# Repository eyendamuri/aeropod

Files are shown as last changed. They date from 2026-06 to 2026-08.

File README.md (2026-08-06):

# aeropod

**A handheld music player built from scratch: custom hardware, custom firmware, custom everything.**

aeropod is an iPod-inspired portable media player built around an ESP32. It has a
capacitive click wheel, a 240×320 colour display, and plays music three different
ways: local files from a microSD card, **Spotify** (both as a Spotify Connect
speaker *and* through the Web API), and as a **Bluetooth speaker** over A2DP. It
even plays MJPEG video. Everything runs on a custom 4-layer circuit board I
designed, inside a 3D-printed case.

<!-- PHOTO: hero shot of the finished aeropod in your hand. Drop the file in docs/images/ and update the path below. -->
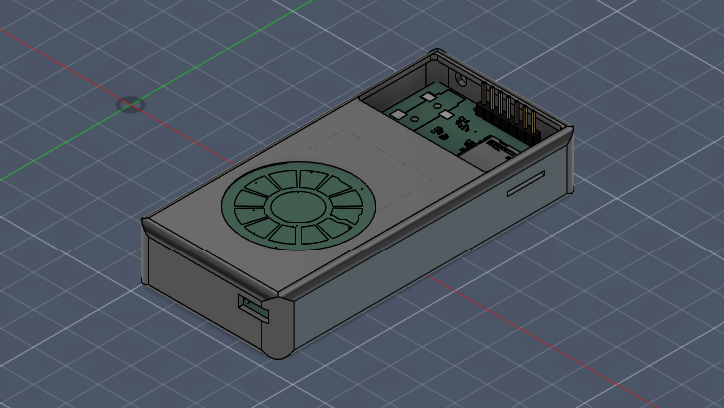
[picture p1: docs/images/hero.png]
aeropod


---

## What it does

- **Local playback**: MP3 / AAC / WAV streamed off a microSD card, browsed by Artist → Album → Track
- **Spotify**: log in once on your phone, then control playback and stream straight to the device. aeropod also announces itself as a **Spotify Connect** target, so you can pick it as a speaker from the Spotify app
- **Bluetooth audio** works both ways: use aeropod as a Bluetooth *speaker* (A2DP sink) from your phone, or have it stream *out* to Bluetooth headphones (A2DP source). AVRCP play/pause/skip supported in both directions
- **Video**: software MJPEG decoding at 240×320, ~10-15 fps, with a synced PCM audio track
- **Click wheel**: a real capacitive touch wheel (MPR121) on its own daughterboard, plus five mechanical buttons, just like the classic
- **iPod-style UI**: stack-based screen system, scrolling menus, now-playing view, a status bar with battery and clock, redrawn at ~33 fps

<!-- PHOTO: the UI on the screen, main menu or now-playing. -->
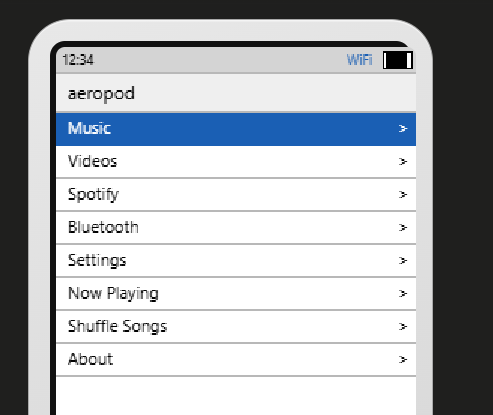
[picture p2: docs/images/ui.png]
UI


---

## Hardware

aeropod is two custom PCBs plus a 3D-printed enclosure.

| Subsystem | Part | Notes |
|---|---|---|
| MCU | **ESP32-WROOM-32** | dual-core, Wi-Fi + Classic Bluetooth |
| Display | **ST7789** 240×320 SPI IPS LCD | PWM backlight |
| Audio DAC | **PCM5102A** | 32-bit I²S stereo DAC |
| Touch input | **MPR121** | 12-zone capacitive click wheel |
| Buttons | 5× tactile | Menu / Prev / Next / Play / Center |
| Storage | microSD (SPI) | FAT, holds the music library |
| Power | USB-C → **TP4056** charger → LiPo → **AMS1117-3.3V** + **MT3608** boost | |

**Main board**: 4-layer, ~41 × 90 mm, 67 components, 147 vias.
**Click wheel board**: the rounded daughterboard that carries the capacitive ring and buttons.

### Pin map

| Peripheral | Pins |
|---|---|
| ST7789 display | SCK 18, MOSI 23, CS 5, DC 17, RST 16, BL 27 |
| microSD (shared SPI bus) | CS 15 |
| PCM5102A I²S | BCK 26, LRCK 25, DATA 22 |
| MPR121 click wheel (I²C) | SDA 21, SCL 4, IRQ 13 |
| Buttons | MENU 34, PREV 35, NEXT 32, PLAY 33, CENTER 39 |

<!-- PHOTO: the bare PCB(s), and/or the board with components soldered. -->
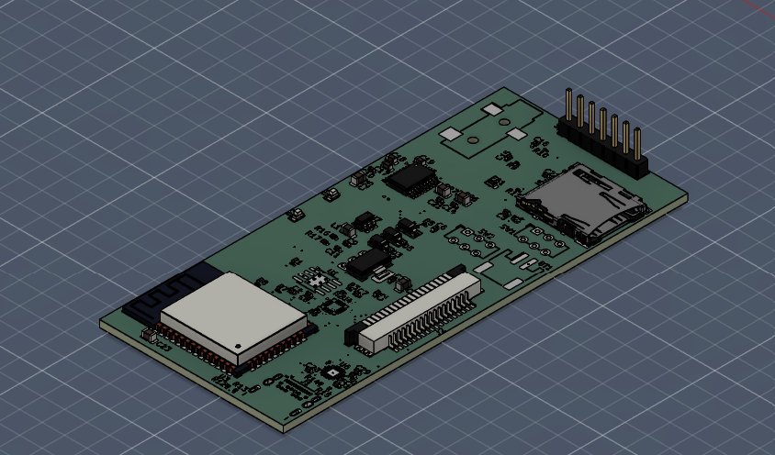
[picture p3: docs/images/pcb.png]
PCB


<!-- PHOTO: the 3D-printed case, printed parts and/or final assembly. -->
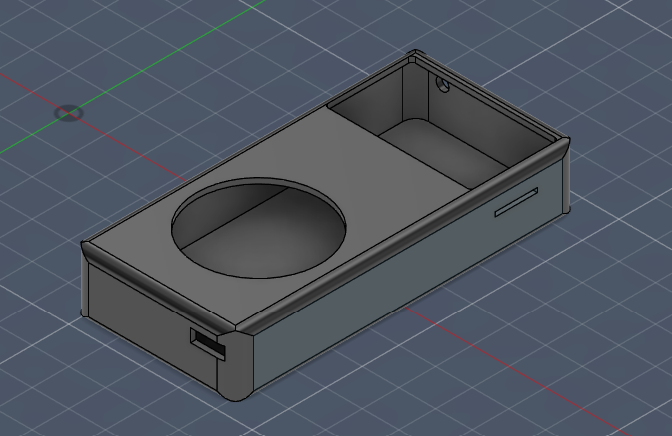
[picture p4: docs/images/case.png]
Case


---

## How the firmware works

The firmware is written in C on **ESP-IDF v5.2+**, about 7,300 lines across a dozen
modules. It's organised so each subsystem (audio, video, Spotify, Bluetooth,
storage, UI) is self-contained.

**Boot sequence:** NVS → display + splash → click-wheel/buttons → SD mount + library
scan → audio player → video player → Wi-Fi → Spotify → Bluetooth → UI.

**Task / core layout:**

| Core | Task | Job |
|---|---|-----|
| 0 | `ui_task` | 33 fps render + input dispatch |
| 0 | `mpr_ring` | MPR121 click-wheel IRQ processing |
| 0 | `cw_btn` | mechanical button polling |
| 1 | `player_task` | MP3 decode (minimp3) + I²S output |
| 0 | `http_fetch` | HTTP audio stream fetch |
| 0 | `sp_connect` | Spotify Connect mDNS + polling |

**Spotify** uses OAuth 2.0 PKCE device-code login (you authorise on your phone, tokens
are saved to NVS and auto-refresh), the Spotify Web API over HTTPS for browse/search/
playback control, and a Spotify Connect receiver that announces over mDNS and decodes
the audio stream to the I²S DAC.

**Bluetooth** uses the ESP32's Classic BT (BR/EDR) stack with A2DP for audio and AVRCP
for transport controls, running alongside Wi-Fi via software coexistence.

---

## Repository layout

```
aeropod/
├── aeropod_firmware/        ESP-IDF firmware (C)
│   ├── main/
│   │   ├── audio/           I²S output + MP3/AAC/WAV player
│   │   ├── bt_audio/        Bluetooth A2DP sink/source + AVRCP
│   │   ├── drivers/         display (ST7789), click wheel (MPR121), fonts
│   │   ├── network/         Wi-Fi manager + HTTP streaming
│   │   ├── spotify/         OAuth PKCE, Web API, Spotify Connect
│   │   ├── storage/         microSD + in-memory media library
│   │   ├── ui/              screen stack + screens (menus, now-playing...)
│   │   ├── video/           MJPEG player (TJpgDec)
│   │   ├── config.h         all hardware pin assignments
│   │   └── main.c           boot + app_main
│   └── BUILD.md             full build instructions
├── aeropod2/                main board - KiCad 10 project + 3D model
│   ├── gerbers/             fabrication gerbers + drill files
│   └── production/          bom.csv, positions.csv (pick & place), JLC-ready zip
├── clickwheel/              click-wheel board - KiCad 10 project + 3D model
│   ├── gerbers/             fabrication gerbers + drill files
│   └── production/          bom.csv, positions.csv (pick & place), JLC-ready zip
├── case/                    printable enclosure - .f3d source, .step, .stl
├── ASSEMBLY.md              how it all goes together
├── bom.csv                  full bill of materials with prices and links
└── aeropod case (Assembly).step   full case assembly model
```

---

## Fabrication and assembly

Everything needed to physically build an aeropod is in the repo:

- **Gerbers**: `aeropod2/gerbers/` and `clickwheel/gerbers/` (drill files included)
- **Pick and place**: `positions.csv` in each board's `production/` folder, plus a ready-to-upload JLCPCB package (`aeropod2.zip` / `clickwheel.zip`)
- **Case**: `case/Aeropod_Case.step`, `case/Aeropod_Case.stl`, and the editable Fusion 360 source `case/Aeropod_Case.f3d`
- **Instructions**: see [`ASSEMBLY.md`](ASSEMBLY.md) for the step-by-step assembly plan

### Bill of materials

Full machine-readable version with links in [`bom.csv`](bom.csv). Prices are
approximate and were checked in August 2026.

| Part | Description | Qty | Unit | Total | Buy |
|---|---|-----|---|---|-----|
| Main board (aeropod2) | 4-layer PCB, 41 x 90 mm, fabricated and assembled, min order 5 | 5 | $23.60 | $118.00 | [JLCPCB](https://jlcpcb.com/) |
| Clickwheel board | 2-layer PCB, fabricated and assembled, min order 5 | 5 | $7.60 | $38.00 | [JLCPCB](https://jlcpcb.com/) |
| ST7789 display module | 2 inch IPS LCD, 240x320, SPI | 1 | $15.99 | $15.99 | [Waveshare](https://www.waveshare.com/2inch-lcd-module.htm) |
| LiPo battery | 3.7 V single cell, 1000 mAh, JST-PH | 1 | $8.99 | $8.99 | [Adafruit](https://www.adafruit.com/product/258) |
| microSD card | 32 GB, Class 10 | 1 | $7.99 | $7.99 | [Amazon](https://www.amazon.com/s?k=32gb+class+10+microsd+card) |
| FFC ribbon cable | 18 pin, 1.0 mm pitch, same-side contacts | 1 | $6.99 | $6.99 | [Amazon](https://www.amazon.com/s?k=18+pin+1.0mm+pitch+ffc+cable) |
| Earbuds or small speaker | 3.5 mm earbuds, or 8 ohm speaker | 1 | $5.99 | $5.99 | [Amazon](https://www.amazon.com/s?k=3.5mm+wired+earbuds) |
| Hot glue gun and sticks | Mounting the main board and battery, closing the case | 1 | $9.99 | $9.99 | [Amazon](https://www.amazon.com/s?k=mini+hot+glue+gun+with+sticks) |
| Cardstock sheet | Backing behind the click-wheel board | 1 | $4.99 | $4.99 | [Amazon](https://www.amazon.com/s?k=cardstock+sheets) |
| 3D printed case | Printed through Hack Club's Printing Legion | 1 | $0.00 | $0.00 | [Printing Legion](https://printinglegion.hackclub.com/) |
| | | | | **$217.92** | |

The parts placed on the two boards (ESP32-WROOM-32, PCM5102A, MPR121, CP2102N,
TP4056, AMS1117, MT3608, connectors, and passives) are covered by the assembly
cost above. They are itemised with individual prices and LCSC links in
[`bom.csv`](bom.csv) in case you want to source them yourself and hand solder.

---

## Building the firmware

Full instructions are in [`aeropod_firmware/BUILD.md`](aeropod_firmware/BUILD.md). Short version:

```bash
# Requires ESP-IDF v5.2+ and an ESP32
. $IDF_PATH/export.sh

cd aeropod_firmware
idf.py set-target esp32
idf.py build
idf.py -p /dev/ttyUSB0 flash monitor   # COMx on Windows
```

Two third-party decoders are downloaded during setup rather than committed here
(see BUILD.md): **minimp3** (MP3) and **TJpgDec** (JPEG/video). For Spotify, register a
free app at the Spotify developer dashboard and drop your Client ID into `config.h`
(or enter it at runtime in Settings).

---

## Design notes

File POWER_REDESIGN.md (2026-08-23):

# aeropod power section, done properly

Guidance only. Nothing in the schematic has been changed.

This describes what the power section should be if you want the whole battery at
high efficiency, rather than any of the patch-ups in `ELECTRICAL_REVIEW.md`. It
is a real redraw of the power block, not a drop-in, but it is the last time you
would have to touch it.

One caveat up front: the TI and Diodes datasheet PDFs are blocked on this
network. Every formula and constant below came from datasheet text quoted in
search results, and the sources are listed at the end, but check the pin numbers
and the TS pin note against the actual PDFs before you order.

---

## Why the current design cannot be rescued

The cell runs 4.2 V down to 3.0 V and the rail you need is 3.3 V. The cell
crosses the output voltage, so no single buck and no single boost covers the
range. There are three honest answers: waste energy converting up then
regulating down, give up part of the discharge curve, or use a buck-boost.

The board does the first, badly. Boost to 5 V at about 88 percent, then an LDO
throwing away the gap from 4.8 V to 3.3 V, is about 60 percent overall. A
buck-boost does the same job in one stage at over 90 percent.

The second problem is the power path. The cell sits directly on the system rail
with the TP4056 charging it in place, so the charger cannot separate load
current from charge current. It never sees the taper that triggers termination,
so it never terminates, the status LED never settles, and if the load exceeds
the charge current the pack quietly discharges while the board says it is
charging.

---

## The architecture

```
USB-C VBUS ──> BQ24074  IN              OUT ──> SYS (3.0 to 4.5 V)
                        BAT <──> LiPo          │
                                               v
                               TPS63020 buck-boost ──> 3.3 V rail
```

Two stages, each doing one job.

**BQ24074** is a 1.5 A linear charger with a real power path. OUT is fed from IN
when USB is present and from BAT when it is not, and it handles that switching
internally. The system runs from USB with no battery fitted, the battery charges
cleanly underneath a running load, and termination works because the charger
sees only charge current.

**TPS63020** is a single-inductor buck-boost. It takes 1.8 V to 5.5 V in and
holds 3.3 V across the whole cell range at over 90 percent.

Everything downstream of the 3.3 V rail is unchanged.

---

## Stage 1: BQ24074 charger

LCSC C54313, part BQ24074RGTR, 16-pin VQFN with a thermal pad.

| Pin | Connect to |
|-----|---|
| IN | VBUS from the USB-C connector, 1 uF ceramic to GND at the pin |
| OUT | SYS rail, 10 uF ceramic to GND |
| BAT | battery positive, 10 uF ceramic to GND |
| VSS and thermal pad | GND, via array into the ground plane |
| CE (active low) | GND, to enable charging |
| ISET | resistor to VSS, sets fast-charge current |
| ILIM | resistor to VSS, sets input current limit |
| TMR | resistor to VSS, sets the safety timer |
| TS | 10 k NTC to VSS, see the note below |
| CHG (active low) | LED cathode; LED anode through 1 k to SYS |
| PGOOD (active low) | second LED, wired the same way |

### Values

**ISET, charge current.** R_ISET = 890 / I_charge, valid 590 ohm to 8.9 k. For
0.5 C on a 1000 mAh cell, so 500 mA:

    R_ISET = 890 / 0.5 = 1.78 k

Use 1.78 k. If you fit a smaller cell, recompute. Never charge a LiPo above 1 C
and 0.5 C is kinder.

**ILIM, input current limit.** R_ILIM = 1550 / I_in_max, valid 1.1 k to 8 k.

    1 A input:  R_ILIM = 1550 / 1.0 = 1.55 k, use 1.5 k
    500 mA:     R_ILIM = 1550 / 0.5 = 3.1 k,  use 3.09 k

Use 1.5 k unless you want to be strictly polite to a USB 2.0 port. Do not leave
ILIM unconnected: that disables charging entirely.

**TMR, safety timer.** R_TMR in kilohms = charge_seconds / (10 x 48). For a
6.25 hour timeout:

    R_TMR = (6.25 x 3600) / 480 = 46.8 k

Use 47 k, and leave the timer enabled. It is the backstop that stops a faulty
cell being charged indefinitely.

**TS, battery temperature.** The intended part is a 10 k NTC, type 103AT-2,
placed touching the cell. On a LiPo sealed inside a 3D printed case, fit it. If
you truly will not use it, the datasheet instruction is a 10 k resistor from TS
to VSS, but confirm that in the PDF, because getting it wrong makes the charger
refuse to start.

**Status LEDs.** Both outputs are open drain and pull low when active, so the
anode goes to SYS through a resistor and the cathode goes to the pin. That is
the opposite of how D1 and D2 are drawn today, which is why they can never
light.

---

## Stage 2: TPS63020 buck-boost

LCSC C15483, part TPS63020DSJR, 14-pin QFN about 3 by 4 mm, thermal pad.

| Pin | Connect to |
|-----|---|
| VIN, VINA | SYS, 2 x 10 uF ceramic to GND at the pins |
| L1, L2 | the two ends of the inductor, nothing else |
| VOUT | 3.3 V rail, 22 uF ceramic to GND |
| FB | midpoint of the feedback divider |
| GND, PGND, thermal pad | GND, joined at the pad, via array into the plane |
| EN | high to run, see the power switch below |
| PS/SYNC | GND, which enables power save mode |
| PG | optional open drain, may be left unconnected |

### Values

**Inductor: 1.5 uH.** TI recommends 1 uH or 1.5 uH for 1.5 A to 2 A output.
Choose a shielded part with at least 2 A saturation current and low DCR, in a
2.5 by 2.0 mm or 3.0 by 3.0 mm body. Saturation current matters more than the
number printed on the label.

**Feedback divider.** Vout = 0.5 x (1 + R1 / R2), with FB at 500 mV nominal, R1
from VOUT to FB and R2 from FB to GND.

    3.3 V needs R1 / R2 = 5.6
    R1 = 560 k, R2 = 100 k  ->  exactly 3.3 V

TI suggests keeping R2 below 500 k and near 200 k so divider current stays well
above the 0.01 uA flowing into FB. 560 k over 100 k draws 5 uA, comfortably
inside that. If you prefer TI's suggested impedance, 1.12 M over 200 k is the
same ratio.

**Capacitors:** 2 x 10 uF input, 22 uF output, X5R or X7R, 10 V rated. Ceramics
lose a large fraction of their value under DC bias, so a 22 uF 6.3 V part at
3.3 V may only be 12 uF in circuit. Use 10 V parts and do not go below what the
datasheet asks.

---

## Battery protection

The cell currently connects straight to the system with nothing protecting it
from over-discharge. Pick one:

- **Buy a protected cell.** Most JST-PH LiPos have a small protection board
  under the tape at the terminals. Simplest and reliable. Confirm it when
  ordering rather than assuming.
- **Put it on the board.** The standard cheap pair is a DW01A protection IC with
  an FS8205A dual N-channel MOSFET, in series with the cell negative terminal.
  About thirty cents.

Do not skip this one. It is the only item in the whole review with a fire on the
other end of it.

---

## Power switch

There is currently no way to turn the device off. This design gives you one
almost free, because the buck-boost has an enable pin.

- 1 M resistor from EN to GND
- SPST slide switch from VINA to EN

Closed is on. Open shuts the converter down to microamps while the charger keeps
working, so the device still charges while it is switched off, which is what you
want.

If you would rather have a soft power button, hold EN up with an ESP32 GPIO and
let the firmware latch itself on. Nicer product, more work. The slide switch is
fine for now.

---

## Battery sensing

BAT is now a separate node from the system rail, so a divider on it reads true
cell voltage instead of whatever the rail happens to be doing.

- 100 k from BAT to the sense node
- 100 k from the sense node to GND
- 100 nF from the sense node to GND
- sense node to a spare ADC1 pin, IO34 or IO35

That takes 4.2 V to 2.1 V, inside the ADC range, and costs 21 uA.

If you want a battery percentage that is believable rather than a voltage guess,
a MAX17048 fuel gauge on the existing I2C bus is about a dollar and roughly ten
times more useful. Optional.

---

## What comes out, what stays

Delete entirely:

| Part | Was |
|---|-----|
| U1, R1 | TP4056 charger and its PROG resistor |
| U2 | AMS1117 regulator |
| U7, L1 | MT3608 boost and its inductor |
| D3, D4, D5 | the diode OR |
| C9, C11 | boost output caps |
| R16, R17 | boost feedback divider |

Keep and reuse:

- J1 USB-C with R12 and R13, the 5.1 k CC resistors, unchanged
- BT1 battery connector, now on BAT rather than on the system rail
- D1, D2 with R2 and R3, reused as charger status, drawn the right way round
- C1 and C2, repurposed as the input and battery capacitors

---

## Layout, which matters more here than the schematic

A buck-boost drawn correctly and laid out badly will be noisy, will regulate to
the wrong voltage, and can oscillate. Five rules:

1. **Keep the inductor loop tiny.** The path from L1 through the inductor to L2
   is the switching node. Short, wide, one layer, no vias. Nothing else touches
   that copper and no sensitive trace runs under it on any layer.
2. **Input and output capacitors go at the pins,** not somewhere convenient. The
   loop from VIN through the cap to PGND, and from VOUT through the cap to PGND,
   carries the current spikes. Loop area is what radiates.
3. **Star the grounds at the thermal pad.** GND and PGND meet under the part and
   drop into the ground plane through a grid of vias, not one via.
4. **Route FB away from the inductor,** and take the top of the divider from the
   output capacitor terminal rather than the IC pin, so the chip regulates the
   voltage the load actually sees.
5. **Put the whole power block far from the wheel connector and the antenna.**
   Twelve capacitive sense lines already share a ribbon with a single ground.
   Putting a 2 MHz switching node next to that connector is the easiest way to
   make the wheel unusable.

Both ICs have thermal pads that are electrically ground and are the main heat
path out of the part. They need vias.

---

## What you get

For a 1000 mAh cell, against the board as it stands:

| | Now | After |
|---|---|---|
| Usable cell range | none on battery, the rail collapses | 4.2 V to 3.0 V |
| Conversion efficiency | about 60 percent even if the boost is repaired | over 90 percent |
| Energy reaching the load | about 2.2 Wh | about 3.4 Wh |
| Charging under load | termination never triggers | correct, power path |
| USB with no battery | works | works |
| Power switch | none | yes |
| Status LEDs | never light | correct |
| Cell protection | none | protected cell or DW01A |

Roughly 55 percent more runtime, and charging behaviour that is correct rather
than merely tolerable.

Cost is about 4 dollars 30 more than the parts it replaces, almost all of it the
two ICs.

---

## Before you order

- Open both datasheets and check pin numbers against the KiCad symbols. The
  tables above are by pin name because I worked from datasheet text, not PDFs.
- Confirm the TS arrangement if you decide not to fit a thermistor.
- Check the inductor saturation current, not just its rated current.
- Check DC bias derating on the 22 uF output capacitor.
- Run ERC, and confirm the feedback node is not routed near the inductor before
  you send it out.

## Sources

- [BQ2407x datasheet, TI](https://www.ti.com/lit/ds/symlink/bq24074.pdf), ISET, ILIM and TMR formulas
- [BQ24074RGTR on LCSC](https://datasheet.lcsc.com/lcsc/1809192125_Texas-Instruments-BQ24074RGTR_C54313.pdf)
- [TPS6302x datasheet, TI](https://www.ti.com/lit/ds/symlink/tps63020.pdf), feedback divider, inductor and capacitor guidance
- [TPS63020 on LCSC](https://datasheet.lcsc.com/datasheet/pdf/271c6fdbdbbe4f399863e9ed77569dc1.pdf?productCode=C15483)

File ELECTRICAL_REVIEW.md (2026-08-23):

# aeropod electrical review and minimum fix list

A net-level review of the main board as it currently stands in this repo. The
schematic here is the original, human-drawn one: the corrected version that was
briefly committed has been reverted, so nothing below is already done.

Findings came from the KiCad netlist exported from the schematic. The point of
this document is the last section: the smallest set of changes that turns this
board into a working one, chosen to disturb the existing layout as little as
possible.

Nothing has been manufactured yet, so all of this is layout editing rather than
cutting traces on a physical board.

---

## What is wrong

### 1. The ESP32 will not boot: EN has no pull-up

SW1 is a SPDT slide switch with its common pin on GND. The 10k pull-up (R4) and
the 100nF (C5) sit on pin A, the position the switch rests in, while EN sits on
pin B. The only other thing on EN is C29, which is AC coupled and cannot hold a
DC level.

So EN floats. The ESP32-WROOM-32 has no internal pull-up on EN and its datasheet
requires an external one, so the module will not start reliably.

### 2. The microSD card cannot work

| Socket pin | SPI function | Wired to | Correct? |
|---|---|---|---|
| 1 DAT2 | unused | IO5 | harmless but wasted |
| 2 DAT3/CD | chip select | IO23 | fine, IO23 can be CS |
| 3 CMD | data in (MOSI) | **GND** | fatal |
| 4 VDD | 3.3 V | 3.3 V | yes |
| 5 CLK | clock | IO18 | yes |
| 6 VSS | ground | GND | yes |
| 7 DAT0 | data out (MISO) | IO19, shared with the display | conflict |
| 8 DAT1 | unused | not connected | yes |

CMD is the line the host sends every command on. Tied to ground, no card will
ever initialise.

Separately, IO19 carries both the card's DAT0 output and the display's data
input. The card only drives DAT0 while it is selected, so this does not
literally short two outputs together, but it does mean the one pin has to be an
input for the card and an output for the display, which a single SPI bus cannot
do.

### 3. The boost converter cannot boost

The MT3608 needs the inductor between the input rail and SW, the Schottky from
SW to the output, and the output cap and feedback divider past the diode.

What is drawn has L1 between SW and a node carrying C9, C11, R16 and the D3
anode, with the battery reaching only the chip's IN pin. There is no DC path
from the battery through the inductor, so there is nothing for the converter to
pump.

### 4. The 3.3 V rail has no headroom on battery

The AMS1117 needs roughly 4.4 V in to hold 3.3 V out under load. Off the cell
through D4 it sees about 3.4 V. The boost was presumably meant to solve this,
but R16 over R17 sets it to about 4.06 V, which is about 3.76 V after D3, still
short. On USB the board is fine, because D5 delivers about 4.7 V.

### 5. The Center button input floats

B5 lands on IO35. GPIO34 to GPIO39 are input only and have no internal pull-up,
and there is no external one, so nothing defines the level when the button is
released.

### 6. The charge LEDs are wired backwards

D1 and D2 have their cathodes on VBUS and their anodes toward R3 and R2, which
go to the TP4056 CHRG and STDBY pins. Those pins sink current when active, so
the LEDs are reverse biased exactly when they are supposed to light. They never
will.

### 7. The DAC is muted in hardware

XSMT on the PCM5102A is an active-low hardware mute with an internal pull-down,
and nothing drives it. No firmware volume setting can override that; the DAC
stays silent.

### 8. The firmware pin map does not match the board

`config.h` disagrees with the schematic on nearly every pin. Only I2S BCK and
LRCK and I2C SDA line up.

### 9. Smaller things

- R1 is 1.2k, setting the TP4056 to about 1 A. That is 1C for a 1000 mAh cell
  and 2C for a 500 mAh one, and the ESOP8 will run hot.
- R9 and R10 are 470 ohm in series with the headphone jack. Into 32 ohm phones
  that is about 24 dB of attenuation.
- The auto-reset circuit cannot work. It needs DTR and RTS, and the CP2102N in
  the 20-pin QFN brings out RTS but not DTR. C30 drives IO0 from CTS, which is
  an input.
- The cell connects straight to the system rail with no over-discharge
  protection.
- Five ERC `power_pin_not_driven` errors. These are the standard missing
  PWR_FLAG complaint on rails fed through a diode, a ferrite or a net tie, not
  wiring faults.

---

## The minimum to make it work

Ordered by how much layout work each one costs. Items marked **free** need no
layout change at all.

### A. Must fix in the layout

**A1. Give EN its pull-up.** Reroute R4 and C5 so they land on SW1 pin B, the
net EN is already on, instead of pin A. Both parts sit right next to SW1, so
this is two short stubs moved by a couple of millimetres. Leave SW1's common on
GND: sliding it then holds EN low, which is your reset.

**A2. Rewire three pins on the microSD socket.** Keep IO19 as the shared MOSI so
the display does not move at all:

| Socket pin | Change |
|---|---|
| 1 DAT2 | disconnect from IO5, leave unconnected |
| 3 CMD | disconnect from GND, connect to IO19 |
| 7 DAT0 | disconnect from IO19, connect to IO5 |

That is two trace endpoints moved between pads on the same connector, plus
deleting one stub to GND. Everything else on the bus stays: IO23 remains chip
select on pin 2, IO18 remains the clock on pin 5, and the display keeps IO19,
IO18, IO15, IO2 and IO32 exactly as they are.

The resulting bus is MOSI on IO19, MISO on IO5, clock on IO18, card select on
IO23, display select on IO15. IO5 is fine as MISO: it is a strapping pin that
must read high at boot, and it will, because the card tri-states DAT0 until it
is selected and IO5 has an internal pull-up.

R11, the 10k on IO19, ends up on MOSI rather than MISO. Harmless. Move it to the
IO5 net if you want it doing its intended job.

**A3. Fix the Center button.** Move the B5 trace at the MCU from IO35 to IO33,
two pads along the same side of the module. IO33 is free and, unlike IO35, has
an internal pull-up, so no resistor is needed. Alternatively fit a 10k from B5
to 3.3 V and leave the routing alone.

### B. Choose one for the power rail

Worth knowing before you spend effort here: **fixing the boost is the worst of
these options for battery life.** The MT3608 lifts the cell to about 5 V at
roughly 88 percent efficiency, and then the AMS1117 burns the gap between 4.8 V
and 3.3 V as heat, losing another 31 percent. Only about 60 percent of the
energy in the cell reaches the load.

Deleting the boost and fitting a real low-dropout regulator gives up the bottom
of the discharge curve but wastes far less on the way, and comes out ahead.
Rough numbers for a 1000 mAh cell (3.7 Wh nominal) at about 250 mA:

| Option | Layout work | Cell used | Efficiency | Energy to load |
|---|---|---|---|---|
| Fix the boost, keep AMS1117 | 3 reroutes | ~100% | ~60% | ~2.2 Wh |
| B1 AP2114H, boost deleted | none | ~78% | ~93% | ~2.7 Wh |
| B2 AP2114H, battery direct | none, one link | ~94% | ~88% | ~3.0 Wh |
| B3 buck-boost module wired in | none | ~100% | ~90% | ~3.3 Wh |
| B4 buck-boost IC on the board | redraw power block | ~100% | ~92% | ~3.4 Wh |

**B1, recommended default: swap the regulator, delete the boost.** No layout
change at all, and it beats the repaired boost on runtime.

- Change U2 from AMS1117-3.3 to **AP2114H-3.3**. Same SOT-223 outline, same
  GND / VOUT / VIN pin order, 450 mV dropout at 1 A against the AMS1117's 1.3 V.
- Mark U7, L1, D3, C9, C11, R16 and R17 do-not-populate.

  **Check the suffix.** The AP2114**H** is GND / VOUT / VIN and drops straight
  into the AMS1117 pads. The AP2114**HA** is VIN / GND / VOUT, a different part
  in the same package, and fitting one will destroy the board. Both are stocked
  and the part numbers differ by one letter.

The rail holds 3.3 V while the cell is above about 3.7 V, then sags gently with
the cell. Everything on the board tolerates that: the ESP32 module is specified
to 3.0 V and the microSD to 2.7 V. The PCM5102A is the tightest at about 3.1 V,
which corresponds to a cell around 3.5 V, so that is where you stop.

**B2, if you want most of the cell: feed the regulator straight from the
battery.** Do B1, and also mark D5 do-not-populate and bridge D4 with a 0 ohm
link. Removing the Schottky drop lets the regulator hold 3.3 V down to a cell of
about 3.4 V and stay usable to about 3.2 V, which is most of the pack.

Two consequences to accept before choosing this:

- The board will no longer run from USB with no battery fitted, because USB then
  only reaches the charger. Awkward for bench work and flashing.
- The TP4056 sees the system load as well as the charge current, so charge
  termination and the status LED become unreliable. Common on hobby boards and
  tolerable, but it is a real compromise.

Do not bridge D4 while leaving D5 fitted. D4 is what stops USB pushing current
backwards into the cell around the charger.

**B3, best runtime without touching the layout: wire in a buck-boost module.**
Mark U2, U7, L1 and D3 do-not-populate and run three wires from a small
buck-boost board, VREGIN in, GND, 3.3 V out, onto the existing pads. Something
like a TPS63020 breakout is roughly 10 by 15 mm and will hold 3.3 V from 4.2 V
all the way down to 3.0 V at around 90 percent. You get the whole cell and good
efficiency for no PCB work, at the cost of a module to find room for in the
case.

**B4, the proper fix for a future revision: a buck-boost IC on the board.** One
part replaces U2, U7, L1 and D3: a TPS63020 or similar takes the cell directly
and produces 3.3 V across the entire discharge range at over 90 percent. This is
what the power section should be if you respin. It needs a new footprint and a
redraw of the power block, so it is not a drop-in.

### C. Free, no layout change

**C1. Rotate D1 and D2 by 180 degrees.** Both are symmetric two-pad parts, so
this swaps the pads without touching a trace, and the status LEDs start working.

**C2. Change resistor values.** R1 from 1.2k to 3k for about 400 mA of charge
current. R9 and R10 from 470 ohm to 33 ohm so headphones are actually audible.
R17 only matters if you repair the boost, which none of the recommended options
do.

**C3. Do not populate C29 and C30.** The auto-reset they were meant to provide
cannot work on this package. Worse, once EN has a proper pull-up, C29 couples
the RTS line onto EN and can cause spurious resets. Flash with the switches
instead: SW2 to the grounded position, tap SW1, put SW2 back.

**C4. Tie the display module's BL pin to 3.3 V.** There is no backlight line on
J6, so the backlight is full brightness and fixed.

**C5. Rewrite the firmware pin map.** With the changes above:

| Signal | Pin |
|---|-----|
| SPI clock | IO18 |
| SPI MOSI | IO19 |
| SPI MISO | IO5 |
| SD card select | IO23 |
| Display select / DC / reset | IO15 / IO2 / IO32 |
| I2S BCK / LRCK / DIN | IO26 / IO25 / IO27 |
| DAC mute, XSMT | IO12 |
| I2C SDA / SCL / IRQ | IO21 / IO22 / IO4 |
| Buttons | IO13, IO14, IO16, IO17, IO33 |

**C6. Drive XSMT high after boot.** Set IO12 as an output and take it high in
the audio init, or the DAC stays muted. Leave it alone before then: IO12 is the
flash voltage strapping pin and must read low at reset, which it will, because
the PCM5102A pulls it down.

### D. Worth doing but skippable

- Buy a LiPo with a protection board already fitted. Most JST-PH cells have one.
  This is the item on the list with a safety consequence, so do not skip it
  casually.
- Add PWR_FLAG symbols on GND, VBUS, the boost output, AVDD and GNDA to clear
  the five ERC errors. Annotation only, no parts, no layout.
- Add a 100k/100k divider from VREGIN into IO34 if you want a real battery
  percentage. IO34 is free. Skip it and the status bar icon stays cosmetic.
- Give the twelve clickwheel electrode zones proper net labels. They work today,
  but they sit on auto-generated `unconnected-(J1-Pin_N-PadN)` net names that a
  future re-annotation could silently detach.

---

## What this leaves

Taking A1 to A3, B1 and all of C: three short reroutes in two small areas of the
board, two parts rotated, three resistor values changed, one regulator swapped
for a different part in the same footprint, seven parts marked do-not-populate,
and a firmware pin map rewrite. No new components, no connector changes, no
boost rework, and the display section untouched.

Interference is unchanged by any of this. The twelve capacitive electrode lines
and five button lines still share an eighteen-pin ribbon with one ground pin,
which remains the part of the design most likely to need attention once there is
hardware to measure. Keep the cable short, and budget time to tune the MPR121
thresholds against the real printed case.

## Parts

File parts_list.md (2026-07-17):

# aeropod parts list (bill of materials)

aeropod is built around two custom printed circuit boards, a small set of
off-the-shelf parts, and a 3D-printed enclosure. This list reflects the current
design in this repository.

## Custom PCBs (fabricated and assembled / PCBA)

Both boards are designed in KiCad 10 (source files in this repo) and ordered as
fabricated-and-assembled boards. I plan to get quotes from both JLCPCB and PCBWay
and order from whichever is cheaper for this design, since both offer turnkey
assembly of the parts below.

Main board (aeropod2), 4-layer, about 41 x 90 mm. Key assembled components:

| Part | Function |
|---|---|
| ESP32-WROOM-32 | MCU, Wi-Fi and Classic Bluetooth |
| PCM5102A | I2S stereo audio DAC |
| TP4056 | single-cell LiPo charge controller (USB-C) |
| AMS1117-3.3 | 3.3 V LDO regulator |
| MT3608 | boost converter |
| USB-C receptacle | charging and flashing |
| microSD socket | card holder (card listed below) |
| Passives | resistors, capacitors, inductors |

Clickwheel board (capacitive wheel plus buttons). Key assembled components:

| Part | Function |
|---|---|
| MPR121 | 12-zone capacitive touch controller |
| 5x tactile switches | Menu, Prev, Next, Play, Center |
| Passives | resistors, capacitors |

## Off-the-shelf parts (sourced separately)

These are not part of the PCB assembly and are bought separately. Exact values
should be confirmed against the final board footprints and your battery space.

| Part | Suggested spec | Function |
|---|---|---|
| ST7789 SPI IPS LCD module | 240x320, about 2 inch (e.g. Waveshare 2" IPS) | display |
| microSD card | 16 to 32 GB, Class 10 | music and video storage |
| LiPo battery | 3.7 V single cell, roughly 500 to 1000 mAh, JST-PH | power |
| FFC/FPC ribbon or jumper wires | matched to the board connectors | links main board to clickwheel board |
| Speaker or headphones | small 8 ohm speaker, or 3.5 mm headphones | audio output |
| Hot glue | standard glue gun sticks | mounting the main board and battery, closing the case |
| Cardstock or thin cardboard | stiff, non-heat-conductive sheet, cut to fit | backing behind the click-wheel board so the buttons have a surface to press against |

## Enclosure (3D printed)

The case cannot be printed in-house, so it will be produced through Hack Club's
Printing Legion, the peer-to-peer printing network for YSWS hardware projects.
The 3D model is in this repo (aeropod case (Assembly).step); an STL can be
exported for printing. Suggested material: PLA or PETG.

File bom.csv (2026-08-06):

Category | Part | Description | Quantity | Unit Price (USD) | Total (USD) | Where to buy
Build cost | Main board (aeropod2) | 4-layer PCB, 41 x 90 mm, fabricated and assembled, minimum order 5 | 5 | 23.60 | 118.00 | https://jlcpcb.com/
Build cost | Clickwheel board | 2-layer PCB, fabricated and assembled, minimum order 5 | 5 | 7.60 | 38.00 | https://jlcpcb.com/
Build cost | ST7789 display module | 2 inch IPS LCD, 240x320, SPI interface | 1 | 15.99 | 15.99 | https://www.waveshare.com/2inch-lcd-module.htm
Build cost | LiPo battery | 3.7 V single cell, 1000 mAh, JST-PH connector | 1 | 8.99 | 8.99 | https://www.adafruit.com/product/258
Build cost | microSD card | 32 GB, Class 10 | 1 | 7.99 | 7.99 | https://www.amazon.com/s?k=32gb+class+10+microsd+card
Build cost | FFC ribbon cable | 18 pin, 1.0 mm pitch, same-side contacts | 1 | 6.99 | 6.99 | https://www.amazon.com/s?k=18+pin+1.0mm+pitch+ffc+cable
Build cost | Earbuds or small speaker | 3.5 mm earbuds, or 8 ohm speaker | 1 | 5.99 | 5.99 | https://www.amazon.com/s?k=3.5mm+wired+earbuds
Build cost | Hot glue gun and sticks | Mounting the main board and battery, closing the case | 1 | 9.99 | 9.99 | https://www.amazon.com/s?k=mini+hot+glue+gun+with+sticks
Build cost | Cardstock sheet | Stiff non-heat-conductive backing behind the click-wheel board | 1 | 4.99 | 4.99 | https://www.amazon.com/s?k=cardstock+sheets
Build cost | 3D printed case | Printed through Hack Club's Printing Legion | 1 | 0.00 | 0.00 | https://printinglegion.hackclub.com/
Build cost | TOTAL |  |  |  | 217.92
Main board component | U3 ESP32-WROOM-32 | MCU module, Wi-Fi and Classic Bluetooth | 1 | 3.20 | included in PCBA | https://www.lcsc.com/search?q=ESP32-WROOM-32
Main board component | U5 PCM5102A | I2S stereo audio DAC, TSSOP-20 | 1 | 1.85 | included in PCBA | https://www.lcsc.com/search?q=PCM5102A
Main board component | U6 CP2102N-Axx-xQFN20 | USB to UART bridge, QFN-20 | 1 | 1.70 | included in PCBA | https://www.lcsc.com/search?q=CP2102N
Main board component | U4 MPR121QR2 | 12-zone capacitive touch controller, UQFN-20 | 1 | 1.15 | included in PCBA | https://www.lcsc.com/search?q=MPR121
Main board component | J5 microSD socket | Hirose DM3AT-SF-PEJM5, push-pull | 1 | 0.62 | included in PCBA | https://www.lcsc.com/search?q=DM3AT-SF-PEJM5
Main board component | J4 3.5 mm audio jack | CUI SJ-3523-SMT, horizontal | 1 | 0.35 | included in PCBA | https://www.lcsc.com/search?q=SJ-3523-SMT
Main board component | J2 FFC connector | 18 pin, 1.0 mm pitch, horizontal | 1 | 0.30 | included in PCBA | https://www.lcsc.com/search?q=1-84953-8
Main board component | U1 TP4056-42-ESOP8 | Single-cell LiPo charge controller | 1 | 0.22 | included in PCBA | https://www.lcsc.com/search?q=TP4056
Main board component | J1 USB-C receptacle | USB 2.0, 14 position | 1 | 0.22 | included in PCBA | https://www.lcsc.com/search?q=USB+C+receptacle+14P
Main board component | U7 MT3608 | Boost converter, SOT-23-6 | 1 | 0.18 | included in PCBA | https://www.lcsc.com/search?q=MT3608
Main board component | SW1 SW2 SPDT switch | E-Switch EG1271, reset and boot | 2 | 0.18 | included in PCBA | https://www.lcsc.com/search?q=EG1271
Main board component | L1 inductor | 4.7 uH, 0805 | 1 | 0.12 | included in PCBA | https://www.lcsc.com/search?q=4.7uH+0805+inductor
Main board component | U2 AMS1117-3.3 | 3.3 V LDO regulator, SOT-223 | 1 | 0.09 | included in PCBA | https://www.lcsc.com/search?q=AMS1117-3.3
Main board component | BT1 JST-PH connector | 2 pin, 2.00 mm, battery | 1 | 0.09 | included in PCBA | https://www.lcsc.com/search?q=S2B-PH-SM4-TB
Main board component | J6 pin header | 7 pin, 2.54 mm, display | 1 | 0.08 | included in PCBA | https://www.lcsc.com/search?q=2.54mm+pin+header
Main board component | D3 D4 D5 Schottky diodes | SOD-123, power path OR-ing | 3 | 0.05 | included in PCBA | https://www.lcsc.com/search?q=SOD-123+schottky
Main board component | D1 D2 LEDs | 0603, charge and standby status | 2 | 0.04 | included in PCBA | https://www.lcsc.com/search?q=0603+LED
Main board component | FB1 ferrite bead | 600 ohm at 100 MHz, 0603 | 1 | 0.03 | included in PCBA | https://www.lcsc.com/search?q=600+ohm+ferrite+bead+0603
Main board component | Capacitors | 0402 / 0603 / 0805, 100nF to 22uF | 27 | 0.02 | included in PCBA | https://www.lcsc.com/search?q=mlcc+capacitor
Main board component | Resistors | 0201 / 0402, 470 ohm to 750k | 16 | 0.01 | included in PCBA | https://www.lcsc.com/search?q=chip+resistor
Clickwheel component | J1 FFC connector | 18 pin, 1.0 mm pitch, horizontal | 1 | 0.30 | included in PCBA | https://www.lcsc.com/search?q=1-84953-8
Clickwheel component | SW1 to SW5 tactile switches | Omron B3S-1000, Menu / Prev / Next / Play / Center | 5 | 0.06 | included in PCBA | https://www.lcsc.com/search?q=B3S-1000

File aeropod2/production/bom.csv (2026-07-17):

Designator | Footprint | Quantity | Value | LCSC Part #
BT1 | JST_PH_S2B-PH-SM4-TB_1x02-1MP_P2.00mm_Horizontal | 1 | Battery_Cell
C1, C10, C14, C2, C21, C22, C28, C29, C3, C30, C31, C7, C8, C9 | 0402 | 14 | 100nF
C11 | 0402 | 1 | 22uF
C15, C16 | 0402 | 2 | 2.2nF
C17, C18, C19 | 0603 | 3 | 2.2uF
C23, C25, C26, C27, C4 | 0805 | 5 | 10uF
C5, C6 | 0402 | 2 | 0.1uF
D1, D2 | 0603 | 2 | LED
D3, D4, D5 | D_SOD-123 | 3 | D_Schottky
FB1 | 0603 | 1 | 600 @ 100 MHz
J1 | USB_C_Receptacle_CNCTech_C-ARA1-AK51X | 1 | USB_C_Receptacle_USB2.0_14P
J2 | TE_1-84953-8_1x18-1MP_P1.0mm_Horizontal | 1 | Conn_01x18
J4 | Jack_3.5mm_CUI_SJ-3523-SMT_Horizontal | 1 | AudioJack3_Ground
J5 | microSD_HC_Hirose_DM3AT-SF-PEJM5 | 1 | Micro_SD_Card
J6 | PinHeader_1x07_P2.54mm_Vertical | 1 | Conn_01x07
L1 | 0805 | 1 | 4.7uH
R1 | 0201 | 1 | 1.2k
R10, R9 | 0201 | 2 | 470
R11, R4, R5 | 0201 | 3 | 10k
R12, R13 | 0201 | 2 | 5.1k
R14 | 0201 | 1 | 22.1k
R15 | 0201 | 1 | 47.5k
R16 | 0402 | 1 | 750k
R17 | 0402 | 1 | 130k
R2, R3 | 0201 | 2 | 1k
R6 | 0201 | 1 | 75k
R7, R8 | 0201 | 2 | 4.7k
SW1, SW2 | SW_E-Switch_EG1271_SPDT | 2 | SW_Push_SPDT
U1 | SOIC-8-1EP_3.9x4.9mm_P1.27mm_EP2.41x3.3mm_ThermalVias | 1 | TP4056-42-ESOP8
U2 | SOT-223-3_TabPin2 | 1 | AMS1117-3.3
U3 | ESP32-WROOM-32 | 1 | ESP32-WROOM-32
U4 | UQFN-20_3x3mm_P0.4mm | 1 | MPR121QR2
U5 | TSSOP-20_4.4x6.5mm_P0.65mm | 1 | PCM5102A
U6 | QFN20_CP2102N_SIL | 1 | CP2102N-Axx-xQFN20
U7 | SOT-23-6 | 1 | MT3608

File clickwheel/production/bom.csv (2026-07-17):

Designator | Footprint | Quantity | Value | LCSC Part #
J1 | TE_1-84953-8_1x18-1MP_P1.0mm_Horizontal | 1 | Conn_01x18
SW1, SW2, SW3, SW4, SW5 | SW_SPST_B3S-1000 | 5 | SW_Push

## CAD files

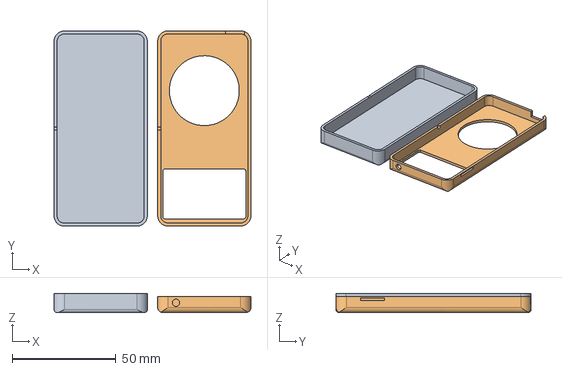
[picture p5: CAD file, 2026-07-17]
case/Aeropod_Case.step
95.0 x 94.2 x 9.30 mm

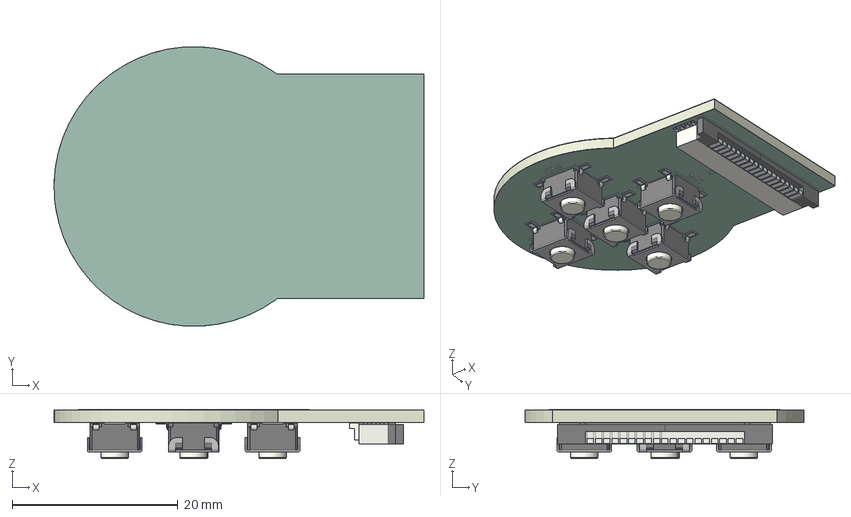
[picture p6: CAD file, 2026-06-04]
clickwheel/clickwheel.step
44.6 x 33.7 x 5.95 mm
SW_SPST_B3S-1000 x 5
TE_1-84953-8_1x18-1MP_P1.0mm_Horizontal
clickwheel_copper
clickwheel_pad
clickwheel_silkscreen
clickwheel_soldermask x 2
clickwheel_PCB

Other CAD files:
case/Aeropod_Case.f3d
case/Aeropod_Case.stl

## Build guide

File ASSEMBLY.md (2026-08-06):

# aeropod assembly guide

How the pieces go together. The boards have not been physically built yet (that
is what this funding round is for), so treat this as the intended assembly plan;
dimensions and fit should be double-checked against the printed case and the
assembled boards when they arrive. Questions welcome.

## 1. What you need

**Fabricated boards** (ordered assembled / PCBA):

| Board | Fab files |
|---|---|
| Main board (aeropod2, 4-layer, ~41 x 90 mm) | `aeropod2/gerbers/` (or `aeropod2/gerbers.zip`), BOM: `aeropod2/production/bom.csv`, pick-and-place: `aeropod2/production/positions.csv`. Ready-to-upload JLC package: `aeropod2/production/aeropod2.zip` |
| Clickwheel board | `clickwheel/gerbers/`, BOM: `clickwheel/production/bom.csv`, pick-and-place: `clickwheel/production/positions.csv`. Ready-to-upload JLC package: `clickwheel/production/clickwheel.zip` |

**Off-the-shelf parts** (see `parts_list.md` for details):

- ST7789 SPI IPS LCD module, 240x320, ~2"
- microSD card (16-32 GB)
- 3.7 V single-cell LiPo, ~500-1000 mAh, JST-PH connector
- FFC/FPC ribbon or jumper wires (main board to clickwheel board)
- Small 8 ohm speaker or 3.5 mm headphones
- Hot glue gun (the main board, battery, and case seam are glued - the PCBs
  have no mounting holes; double-sided tape works for the battery too)
- A piece of cardstock or thin cardboard (or any similar stiff,
  non-heat-conductive sheet) - backing for the click-wheel board

**Printed case**: `case/Aeropod_Case.stl` for printing, `case/Aeropod_Case.step`
for CAD import, and `case/Aeropod_Case.f3d` if you want to edit the original
Fusion 360 model. The STL contains both shells laid out flat for printing
(overall ~95 x 94 mm plate, 9.3 mm tall). PLA or PETG, no supports should be
needed in this orientation.

## 2. Order the boards

Upload `aeropod2/production/aeropod2.zip` and
`clickwheel/production/clickwheel.zip` to JLCPCB (or use the loose gerbers +
`bom.csv` + `positions.csv` with any fab that does turnkey assembly). Everything
in the BOM is placed by the fab; the display module, battery, and SD card are
the only things added by hand later.

## 3. Print the case

Print `case/Aeropod_Case.stl` as-is (both halves are on one plate). Suggested
0.2 mm layers, 3 walls, PLA or PETG. If your slicer reports the model in the
wrong scale, the source of truth is the STEP file: the plate is 95 x 94.2 mm.

## 4. Flash the firmware (before final assembly)

Easier to do while the board is still bare:

1. Install ESP-IDF v5.2+ and follow `aeropod_firmware/BUILD.md`.
2. Connect USB-C, then `idf.py -p COMx flash`.
3. Optional: put a few MP3s on the microSD card now so there is something to
   play on first boot.

## 5. Put it together

Approximate order (refine against the real parts):

1. **Display into the front shell.** The ST7789 module sits behind the
   rectangular window in the front shell. Seat it in the recess; a couple of
   small dabs of hot glue or double-sided tape on the module edges (not the
   flex) hold it fine.
2. **Clickwheel board into the front shell.** It sits in the circular recess
   below the display window, component side facing away from your thumb (the
   electrode side must face the front surface, as close to the plastic as
   possible - capacitive sensing works through the shell). This board is NOT
   glued down. Cut a piece of cardstock or thin cardboard to the shape of the
   recess and place it behind the board, so the tactile buttons have a firm
   surface to push against; the board is held by pressure between the front
   shell and that backing sheet. To stop it sliding sideways, put small hot
   glue dams on the case around the board's edge (glue on the plastic, not on
   the board). Note that this backing is not modeled in the case - its
   thickness is not hardcoded anywhere - so stack layers of cardstock until
   the wheel sits flush with light, even pressure and the buttons click
   cleanly.
3. **Connect the wheel to the main board.** FFC ribbon or short jumper wires
   between the wheel connector on each board (I2C: SDA/SCL, IRQ, 3.3 V, GND,
   plus the five button lines - the connectors are labelled on the silkscreen).
4. **Main board into the back shell.** USB-C and the microSD slot line up with
   the cutouts on the bottom edge. Seat the board on the internal posts and
   tack the corners with hot glue - the board has no mounting holes, so glue
   is the mounting plan.
5. **Connect the display cable** from the front shell to the display connector
   on the main board (SPI: SCK/MOSI/CS/DC/RST plus backlight, labelled on
   silkscreen).
6. **Battery.** The LiPo plugs into the JST-PH connector on the main board and
   sits in its pocket next to the board (double-sided tape). Make sure the
   polarity of your battery lead matches the board silkscreen before plugging
   it in - JST-PH pigtails from different vendors are wired both ways.
7. **Close it up.** The front and back shells locate on a lip around the rim.
   Check no wires are pinched, press the halves together, and run a few dabs
   of hot glue along the inside of the seam - dabs at the corners rather than
   a full bead if you want to be able to pry it open again later.
8. **First boot:** hold nothing, plug USB-C or tap the power switch; you should
   see the splash and then the main menu. Wheel sensitivity is tuned in
   firmware (`aeropod_firmware/main/drivers/clickwheel.c`), so if the wheel
   feels dead or jumpy through your print, adjust the MPR121 thresholds there.

## Known unknowns

Honest list of things that will only be confirmed with hardware in hand: exact
LiPo pocket fit for larger cells, whether the wheel needs threshold retuning
through the printed shell thickness, and how many layers of cardstock give the
wheel board the right button feel (the backing is deliberately not part of the
case model, so it is tuned by hand). This section gets updated after the first
physical build.

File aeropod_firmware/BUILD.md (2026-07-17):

# aeropod firmware - build guide

## Prerequisites

- **ESP-IDF v5.2+** - https://docs.espressif.com/projects/esp-idf/en/latest/
- **Target**: ESP32 (ESP32-WROOM-32 on aeropod2 board)

```bash
. $IDF_PATH/export.sh   # activate IDF environment
```

## Third-party dependencies (download before building)

### 1. minimp3 (MP3 decoder)
```bash
wget https://raw.githubusercontent.com/lieff/minimp3/master/minimp3.h \
     -O main/audio/minimp3.h
```

### 2. TJpgDec (JPEG/video decoder)
```bash
# Download tjpgd.c and tjpgd.h from elm-chan.org
wget http://elm-chan.org/fsw/tjpgd/arc/tjpgd030.zip
unzip tjpgd030.zip src/tjpgd.c src/tjpgd.h -d /tmp/
cp /tmp/src/tjpgd.c main/video/
cp /tmp/src/tjpgd.h main/video/
# Remove the stub header included in the repo
rm -f main/video/tjpgd.h   # already downloaded above
```

Then update `main/CMakeLists.txt` to add `"video/tjpgd.c"` to SRCS.

## Build

```bash
cd aeropod_firmware
idf.py set-target esp32
idf.py menuconfig      # optional: review sdkconfig
idf.py build
```

## Flash & monitor

```bash
idf.py -p /dev/ttyUSB0 flash monitor
```

(Replace `/dev/ttyUSB0` with your port, e.g. `COM4` on Windows.)

---

## Hardware pin summary (aeropod2 rev)

| Peripheral | Pins |
|---|---|
| ST7789 IPS display| SCK=18, MOSI=23, CS=5, DC=17, RST=16, BL=27  |
| SD card (SPI) | shared VSPI bus, CS=15 |
| PCM5102A I2S | BCK=26, LRCK=25, DATA=22 |
| MPR121 clickwheel | SDA=21, SCL=4, IRQ=13 |
| Buttons | MENU=34, PREV=35, NEXT=32, PLAY=33, CTR=39 |

Pin assignments are centralised in `main/config.h` - adjust for your layout.

---

## SD card media format

Place files anywhere under the SD root:
```
/sdcard/
  Music/
    Artist Name/
      Album Name/
        01 - Track.mp3
  Videos/
    clip.mjpeg       ← raw MJPEG with 4-byte size prefix per frame
    movie.avi        ← MJPEG inside AVI container
```

Audio formats supported: `.mp3`, `.wav`, `.aac` (AAC via libhelix - future), `.flac`  
Video formats: `.mjpeg` / `.mjpg` (custom container), `.avi` (MJPEG video stream)

---

## Video encoding for aeropod

Convert any video to aeropod MJPEG format using FFmpeg:

```bash
# 240×320, 10fps, quality 5 (1=best, 31=worst)
ffmpeg -i input.mp4 \
       -vf "scale=240:320:force_original_aspect_ratio=decrease,pad=240:320:(ow-iw)/2:(oh-ih)/2" \
       -r 10 -q:v 5 \
       -f mjpeg -an output_raw.mjpeg

# Prepend aeropod container header (Python one-liner)
python3 -c "
import struct, sys
frames = open('output_raw.mjpeg','rb').read().split(b'\xff\xd9')
frames = [f+b'\xff\xd9' for f in frames if f.startswith(b'\xff\xd8')]
out = open('output.mjpeg','wb')
out.write(b'MJPG')
out.write(struct.pack('<II', 10, len(frames)))  # fps=10, nframes
for f in frames:
    out.write(struct.pack('<I', len(f)))
    out.write(f)
print(f'Written {len(frames)} frames')
"
```

---

## Internet radio streams

Built-in stations are defined in `main/network/http_stream.c` (`s_defaults[]`).  
Add custom streams via Settings → WiFi → (future: Add Stream), or edit the array.

All streams use HTTP MP3 (Shoutcast/ICY compatible).

---

## Spotify setup

1. Go to https://developer.spotify.com/dashboard and create an app.
2. Add `http://localhost` as a Redirect URI (not used but required by Spotify).
3. Copy your **Client ID** into `main/config.h`:
   ```c
   #define SPOTIFY_CLIENT_ID  "your_client_id_here"
   ```
4. On first boot, open **Spotify** from the main menu. The screen shows a URL
   (`spotify.com/pair`) and a 6-character code. Enter these on any browser.
5. Tokens are saved to NVS - you only authenticate once.

**Spotify Connect**: After login, aeropod appears as a device named "aeropod"
in your Spotify app's device list. Tap it to transfer playback directly.

---

## Bluetooth audio setup

**Sink mode** (aeropod as speaker):
- Open your phone's Bluetooth settings and pair with "aeropod".
- Audio streams directly to the PCM5102A DAC.

**Source mode** (aeropod → BT headphones):
- In the app, go to **Bluetooth → Headphones tab** and press Select to scan.
- Select your headphones from the list.
- AVRCP controls (play/pause/skip) work via the physical buttons.

---

## Clickwheel ring zones

```
            ELE0 (0°)     ← MENU button position
       ELE11     ELE1
     ELE10         ELE2
    ELE9 (270°)   ELE3 (90°)   ← PREV / NEXT button positions
     ELE8          ELE4
       ELE7      ELE5
            ELE6 (180°)   ← PLAY button position
```

- 12 electrodes × 30° = full 360° ring
- ELE0–ELE11 mapped from MPR121 pins 8–19
- Centroid algorithm gives sub-30° resolution
- 24 ticks per full rotation (default), adjustable via `clickwheel_set_sensitivity()`

---

## Architecture overview

```
app_main()
  ├── display_init()         → ST7789 SPI @ 40 MHz, LEDC backlight
  ├── clickwheel_init()      → MPR121 12-zone ring + 5 mechanical buttons
  │                            cw_event_t queue (CW_ROTATE_CW/CCW, CW_BTN_*)
  ├── sdcard_init()          → FAT/SDMMC mount at /sdcard
  ├── media_db_scan()        → Artist/Album/Track in-memory DB (ID3v1 tags)
  ├── player_init()          → I2S PCM5102A + minimp3 decode (Core 1)
  ├── video_player_init()    → TJpgDec MJPEG decoder
  ├── wifi_manager_init()    → NVS credentials, background connect
  ├── spotify_init()         → OAuth2 PKCE, Web API, Connect mDNS (Core 0)
  ├── bt_audio_init()        → A2DP Sink + AVRCP (Classic BT, coexist w/ WiFi)
  └── ui_task (Core 0, 33 fps)
        ├── clickwheel queue → ui_dispatch_input(cw_event_t)
        └── ui_render()
              └── screen stack
                    SCREEN_MAIN_MENU      Music / Videos / Spotify / BT / Settings
                    SCREEN_MUSIC_MENU     Artists → Albums → Songs
                    SCREEN_NOW_PLAYING    progress, volume dots, shuffle/repeat
                    SCREEN_SPOTIFY        OAuth, My Playlists, Featured, Connect NP
                    SCREEN_BLUETOOTH      Sink (speaker) / Source (headphones)
                    SCREEN_SETTINGS       WiFi, brightness, sensitivity, factory reset
                    SCREEN_VIDEO_PLAYER   MJPEG/AVI file list + playback
                    SCREEN_ABOUT          hardware info, track counts
```

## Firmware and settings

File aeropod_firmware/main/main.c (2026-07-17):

/**
 * aeropod_firmware - app_main entry point
 *
 * Boot sequence:
 *   1. NVS init
 *   2. Display init + splash
 *   3. Clickwheel / button driver init  (12-zone MPR121 ring + 5 mechanical btns)
 *   4. SD card mount + media library scan
 *   5. Audio player init (I2S PCM5102A + minimp3)
 *   6. Video player init (TJpgDec MJPEG)
 *   7. WiFi manager init (lazy connect from NVS)
 *   8. Spotify init  (restore tokens from NVS, start Connect mDNS)
 *   9. Bluetooth audio init  (A2DP sink - aeropod as BT speaker)
 *  10. UI init + register all screens → push Main Menu
 *  11. Launch UI task (Core 0, 33 fps render + input dispatch)
 *
 * Task / core map:
 *   Core 0:  ui_task (prio 5)
 *   Core 0:  mpr_ring task (prio 10)  - MPR121 IRQ processing
 *   Core 0:  cw_btn task   (prio  9)  - mechanical button poll
 *   Core 1:  player_task   (prio  8)  - minimp3 decode + I2S write
 *   Core 0:  http_fetch    (prio  6)  - HTTP audio stream fetch
 *   Core 0:  sp_connect    (prio  5)  - Spotify Connect mDNS + poll
 */

#include "config.h"
#include "drivers/display.h"
#include "drivers/clickwheel.h"
#include "audio/player.h"
#include "storage/sdcard.h"
#include "storage/media_db.h"
#include "network/wifi_manager.h"
#include "spotify/spotify.h"
#include "bt_audio/bt_audio.h"
#include "ui/ui.h"
#include "ui/screens/main_menu.h"
#include "ui/screens/music_menu.h"
#include "ui/screens/now_playing.h"
#include "ui/screens/settings.h"
#include "video/video_player.h"

#include "esp_log.h"
#include "esp_system.h"
#include "esp_random.h"
#include "nvs_flash.h"
#include "freertos/FreeRTOS.h"
#include "freertos/task.h"
#include <string.h>
#include <stdio.h>

static const char *TAG = APP_TAG;

// ─── Forward declarations ─────────────────────────────────────────────────────
extern screen_t *spotify_screen(void);
extern screen_t *bt_audio_screen(void);
extern screen_t *video_player_screen(void);

// ─── About screen (inline, no separate file needed) ──────────────────────────
static void about_render(screen_t *self)
{
    display_clear(COL_WHITE);
    int16_t hy = STATUS_BAR_H;
    display_fill_rect(0, hy, LCD_WIDTH, 24, 0xEF7D);
    display_draw_hline(0, hy + 23, LCD_WIDTH, COL_GRAY_LINE);
    display_draw_string(4, hy + 5, "<", FONT_MEDIUM, COL_BLUE_SEL, 0xEF7D);
    display_draw_string_centred(0, hy + 5, LCD_WIDTH, "About", FONT_MEDIUM, COL_BLACK, 0xEF7D);

    int16_t y = hy + 42;
    display_draw_string_centred(0, y,      LCD_WIDTH, "aeropod",       FONT_LARGE,  COL_BLACK,     COL_WHITE);
    display_draw_string_centred(0, y + 26, LCD_WIDTH, "fw v" FW_VERSION, FONT_SMALL, COL_DARK_TEXT, COL_WHITE);

    display_draw_hline(20, y + 42, LCD_WIDTH - 40, COL_GRAY_LINE);

    display_draw_string_centred(0, y + 50, LCD_WIDTH, "ESP32-WROOM-32",     FONT_SMALL, COL_DARK_TEXT, COL_WHITE);
    display_draw_string_centred(0, y + 64, LCD_WIDTH, "PCM5102A I2S DAC",   FONT_SMALL, COL_DARK_TEXT, COL_WHITE);
    display_draw_string_centred(0, y + 78, LCD_WIDTH, "ST7789 IPS 240\xd7 320", FONT_SMALL, COL_DARK_TEXT, COL_WHITE);
    display_draw_string_centred(0, y + 92, LCD_WIDTH, "MPR121 12-zone ring", FONT_SMALL, COL_DARK_TEXT, COL_WHITE);

    display_draw_hline(20, y + 108, LCD_WIDTH - 40, COL_GRAY_LINE);

    const media_db_t *db = media_db_get();
    char buf[40];
    snprintf(buf, sizeof(buf), "%u tracks  %u albums  %u artists",
             db->track_count, db->album_count, db->artist_count);
    display_draw_string_centred(0, y + 116, LCD_WIDTH, buf, FONT_SMALL, COL_DARK_TEXT, COL_WHITE);

    display_draw_string_centred(0, LCD_HEIGHT - 14, LCD_WIDTH,
                                "MENU = back", FONT_SMALL, COL_GRAY_LINE, COL_WHITE);
}

static void about_input(screen_t *self, const cw_event_t *evt)
{
    if (evt->type == CW_BTN_MENU || evt->type == CW_BTN_CENTER)
        ui_pop_screen();
}

static void about_enter(screen_t *self, void *p) { ui_invalidate(); }

static screen_t s_about_screen = {
    .id       = SCREEN_ABOUT,
    .enter    = about_enter,
    .render   = about_render,
    .on_input = about_input,
    .exit     = NULL,
    .priv     = NULL,
};

// ─── Splash screen ────────────────────────────────────────────────────────────
static uint8_t s_splash_progress = 0;

static void draw_splash(const char *msg)
{
    display_clear(COL_BLACK);
    display_draw_string_centred(0, LCD_HEIGHT/2 - 30, LCD_WIDTH,
                                "aeropod", FONT_LARGE, COL_WHITE, COL_BLACK);
    display_draw_string_centred(0, LCD_HEIGHT/2 + 2,  LCD_WIDTH,
                                msg, FONT_SMALL, 0x7BEF, COL_BLACK);
    // Animated progress bar
    s_splash_progress += 12;
    if (s_splash_progress > 100) s_splash_progress = 100;
    display_fill_rect(0, LCD_HEIGHT - 5, LCD_WIDTH, 5, 0x2945);
    display_fill_rect(0, LCD_HEIGHT - 5,
                      (int16_t)(LCD_WIDTH * s_splash_progress / 100), 5, COL_BLUE_SEL);
}

// ─── Event callbacks ──────────────────────────────────────────────────────────
static void on_wifi_event(wifi_event_id_t evt, const char *info)
{
    if (evt == WIFI_EVT_GOT_IP)
        ESP_LOGI(TAG, "WiFi connected: %s", info ? info : "");
    ui_invalidate();
}

static void on_player_event(const player_status_t *st)
{
    ESP_LOGI(TAG, "Track: %s - %s [%s]",
             st->artist, st->title,
             st->state == PLAYER_STATE_PLAYING ? "play" : "stop");
    ui_invalidate();
}

static void on_spotify_event(spotify_event_t evt, const spotify_status_t *st)
{
    switch (evt) {
        case SPOTIFY_EVT_AUTH_NEEDED:
            ESP_LOGI(TAG, "Spotify auth needed → %s  code: %s",
                     st->auth_url, st->auth_code);
            break;
        case SPOTIFY_EVT_AUTH_OK:
            ESP_LOGI(TAG, "Spotify authenticated");
            break;
        case SPOTIFY_EVT_TRACK_CHANGED:
            ESP_LOGI(TAG, "Spotify track: %s - %s", st->track.artists, st->track.name);
            break;
        default: break;
    }
    ui_invalidate();
}

static void on_bt_event(bt_state_t state, const bt_status_t *st)
{
    ESP_LOGI(TAG, "BT state: %d  device: %s", state, st->connected_device.name);
    ui_invalidate();
}

// ─── UI task ─────────────────────────────────────────────────────────────────
static void ui_task(void *arg)
{
    QueueHandle_t input_q = clickwheel_get_queue();
    cw_event_t    evt;
    TickType_t    render_tick = xTaskGetTickCount();

    while (true) {
        // Drain all pending input events before rendering
        while (xQueueReceive(input_q, &evt, 0) == pdTRUE)
            ui_dispatch_input(&evt);

        // 33 fps render cadence
        TickType_t now = xTaskGetTickCount();
        if (now - render_tick >= pdMS_TO_TICKS(30)) {
            ui_render();
            render_tick = now;
        }
        vTaskDelay(pdMS_TO_TICKS(5));
    }
}

// ─── app_main ─────────────────────────────────────────────────────────────────
void app_main(void)
{
    ESP_LOGI(TAG, "aeropod v" FW_VERSION " - booting");

    // ── 1. NVS ────────────────────────────────────────────────────────────────
    esp_err_t err = nvs_flash_init();
    if (err == ESP_ERR_NVS_NO_FREE_PAGES || err == ESP_ERR_NVS_NEW_VERSION_FOUND) {
        ESP_LOGW(TAG, "NVS: erasing partition");
        nvs_flash_erase();
        nvs_flash_init();
    }

    // ── 2. Display + splash ───────────────────────────────────────────────────
    display_init();
    draw_splash("Starting up...");

    // ── 3. Clickwheel ─────────────────────────────────────────────────────────
    draw_splash("Clickwheel...");
    ESP_ERROR_CHECK(clickwheel_init());
    // Default: 24 ticks per full rotation → ~15° per step
    clickwheel_set_sensitivity(24);

    // ── 4. SD card + media scan ───────────────────────────────────────────────
    draw_splash("SD card...");
    err = sdcard_init();
    if (err == ESP_OK) {
        draw_splash("Scanning music...");
        media_db_scan();
        const media_db_t *db = media_db_get();
        ESP_LOGI(TAG, "Media: %u tracks, %u albums, %u videos",
                 db->track_count, db->album_count, db->video_count);
    } else {
        ESP_LOGW(TAG, "No SD card - music/video disabled");
    }

    // ── 5. Audio player ───────────────────────────────────────────────────────
    draw_splash("Audio...");
    ESP_ERROR_CHECK(player_init());
    player_set_event_callback(on_player_event);

    // ── 6. Video player ───────────────────────────────────────────────────────
    video_player_init();

    // ── 7. WiFi (lazy - connect in background using NVS creds) ───────────────
    draw_splash("Network...");
    wifi_manager_init(on_wifi_event);
    wifi_manager_connect();   // non-blocking; fails silently if no saved creds

    // ── 8. Spotify ────────────────────────────────────────────────────────────
    draw_splash("Spotify...");
    // Client ID: set SPOTIFY_CLIENT_ID in config.h or via spotify_init() arg
    spotify_init(SPOTIFY_CLIENT_ID[0] ? SPOTIFY_CLIENT_ID : NULL,
                 on_spotify_event);
    spotify_set_device_name("aeropod");
    // Start Connect mDNS announcement (background task)
    spotify_connect_start();

    // ── 9. Bluetooth audio (sink mode - appears as BT speaker) ───────────────
    draw_splash("Bluetooth...");
    // BT and WiFi coexistence: ESP32 supports both simultaneously via coex
    bt_audio_init(BT_MODE_SINK, on_bt_event);
    bt_sink_set_discoverable(true);

    // ── 10. UI ────────────────────────────────────────────────────────────────
    draw_splash("Ready!");
    vTaskDelay(pdMS_TO_TICKS(300));

    ui_init();

    // Register all screens
    ui_register_screen(main_menu_screen());
    ui_register_screen(music_menu_screen());
    ui_register_screen(now_playing_screen());
    ui_register_screen(settings_screen());
    ui_register_screen(spotify_screen());      // SCREEN_SPOTIFY
    ui_register_screen(bt_audio_screen());     // SCREEN_BLUETOOTH
    ui_register_screen(video_player_screen()); // SCREEN_VIDEO_PLAYER
    ui_register_screen(&s_about_screen);       // SCREEN_ABOUT

    // Fix bt_screen's placeholder ID
    bt_audio_screen()->id = SCREEN_BLUETOOTH;

    // Boot into main menu
    ui_push_screen(SCREEN_MAIN_MENU, NULL);

    ESP_LOGI(TAG, "Boot complete - free heap: %lu bytes",
             (unsigned long)esp_get_free_heap_size());

    // ── 11. UI task ───────────────────────────────────────────────────────────
    xTaskCreatePinnedToCore(ui_task, "ui", 8192, NULL, 5, NULL, 0);

    // app_main returns; its task is deleted by ESP-IDF
}

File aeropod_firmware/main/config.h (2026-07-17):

#pragma once

/**
 * aeropod_firmware - hardware configuration
 *
 * MCU   : ESP32-WROOM-32 (aeropod2 schematic: esp32.kicad_sch)
 * Audio : PCM5102A stereo DAC via I2S  (audio.kicad_sch)
 * Input : MPR121QR2 capacitive clickwheel (I2C) + 5 push buttons (input.kicad_sch)
 * Display: ST7789 240×320 SPI IPS LCD  (display.kicad_sch - Conn_01x07)
 * Storage: Micro-SD card in SPI mode (storage.kicad_sch)
 * Power : USB-C → TP4056 → LiPo → AMS1117-3.3V + MT3608 boost (power.kicad_sch)
 */

// ─── Display (ST7789, SPI via VSPI) ──────────────────────────────────────────
#define LCD_WIDTH        240
#define LCD_HEIGHT       320
#define LCD_SPI_HOST     SPI3_HOST     // VSPI
#define LCD_CLK_PIN      GPIO_NUM_18
#define LCD_MOSI_PIN     GPIO_NUM_23
#define LCD_MISO_PIN     GPIO_NUM_19   // optional; MISO unused for writes
#define LCD_CS_PIN       GPIO_NUM_5
#define LCD_DC_PIN       GPIO_NUM_17
#define LCD_RST_PIN      GPIO_NUM_16
#define LCD_BL_PIN       GPIO_NUM_27   // PWM backlight (LEDC channel 0)
#define LCD_SPI_FREQ_HZ  (40 * 1000 * 1000)
#define LCD_DMA_CHAN     1

// DMA line-buffer: 240 pixels × 2 bytes (RGB565) × 8 lines
#define LCD_BUF_LINES    8
#define LCD_BUF_SIZE     (LCD_WIDTH * LCD_BUF_LINES * 2)

// ─── SD Card (SPI, shared bus with LCD, separate CS) ─────────────────────────
#define SD_SPI_HOST      SPI3_HOST    // same bus, different CS
#define SD_CS_PIN        GPIO_NUM_15
#define SD_SPI_FREQ_HZ   (20 * 1000 * 1000)
#define SD_MOUNT_POINT   "/sdcard"

// ─── PCM5102A I2S Audio DAC ───────────────────────────────────────────────────
#define I2S_NUM          I2S_NUM_0
#define I2S_BCK_PIN      GPIO_NUM_26   // Bit clock
#define I2S_LRCK_PIN     GPIO_NUM_25   // Word select (L/R clock)
#define I2S_DOUT_PIN     GPIO_NUM_22   // Data out to DAC
#define I2S_SAMPLE_RATE  44100
#define I2S_BITS         32            // PCM5102A is 32-bit I2S
#define I2S_CHANNELS     2
#define I2S_DMA_BUF_LEN  1024
#define I2S_DMA_BUF_CNT  4

// ─── MPR121 Capacitive Clickwheel (I2C) ──────────────────────────────────────
#define I2C_PORT         I2C_NUM_0
#define I2C_SDA_PIN      GPIO_NUM_21
#define I2C_SCL_PIN      GPIO_NUM_4    // avoids conflict with I2S/SPI
#define I2C_FREQ_HZ      400000        // 400 kHz fast mode
#define MPR121_ADDR      0x5A          // ADDR pin = GND
#define MPR121_IRQ_PIN   GPIO_NUM_13   // active low interrupt

// MPR121 electrode → clickwheel position mapping
// Electrodes 0-3 = outer ring (N, E, S, W)
// Electrodes 4-7 = inner ring quadrants
// Electrode 8    = center touch area
#define CW_EL_NORTH      0
#define CW_EL_EAST       1
#define CW_EL_SOUTH      2
#define CW_EL_WEST       3
#define CW_EL_CENTER     8
#define CW_NUM_ELECTRODES 12

// ─── Physical Buttons (active low, pulled high) ───────────────────────────────
// SW1..SW5 on clickwheel PCB, routed through 18-pin connector
#define BTN_MENU_PIN     GPIO_NUM_34   // input only
#define BTN_PREV_PIN     GPIO_NUM_35   // input only
#define BTN_NEXT_PIN     GPIO_NUM_32
#define BTN_PLAY_PIN     GPIO_NUM_33
#define BTN_CENTER_PIN   GPIO_NUM_39   // SENSOR_VN - input only, no pull
#define BTN_DEBOUNCE_MS  30

// ─── Battery ADC ─────────────────────────────────────────────────────────────
// Voltage divider on VBAT → ADC1 channel 6 (GPIO34 shared with MENU btn)
// If MENU btn uses GPIO34, use a different pin for VBAT in hardware revision
#define VBAT_ADC_CHANNEL ADC1_CHANNEL_7   // GPIO35 if not used by button
#define VBAT_FULL_MV     4200
#define VBAT_EMPTY_MV    3300

// ─── UI Geometry ─────────────────────────────────────────────────────────────
#define STATUS_BAR_H     18            // top status bar height (px)
#define MENU_ITEM_H      22            // height of one menu row
#define MENU_VISIBLE     (((LCD_HEIGHT - STATUS_BAR_H) / MENU_ITEM_H))  // ~13
#define ALBUM_ART_SIZE   LCD_WIDTH     // square album art when available

// ─── iPod Classic Color Palette (RGB565) ─────────────────────────────────────
#define COL_WHITE        0xFFFF
#define COL_BLACK        0x0000
#define COL_BLUE_SEL     0x035F        // selection highlight blue
#define COL_GRAY_STATUS  0xC618        // status bar background
#define COL_GRAY_LINE    0x8410        // separator lines
#define COL_DARK_TEXT    0x2104        // secondary text
#define COL_ORANGE_ACC   0xFD20        // accent (battery, now-playing dot)

// ─── Spotify ─────────────────────────────────────────────────────────────────
// Register your app at https://developer.spotify.com/dashboard
// then paste your Client ID here (or leave blank to enter at runtime via Settings).
#define SPOTIFY_CLIENT_ID   ""   // e.g. "abc123def456..."

// ─── Application ─────────────────────────────────────────────────────────────
#define APP_TAG          "aeropod"
#define FW_VERSION       "1.0.0"
#define NVS_NAMESPACE    "aeropod"
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

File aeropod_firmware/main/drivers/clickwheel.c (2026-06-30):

#include "clickwheel.h"
#include "config.h"
#include "driver/i2c.h"
#include "driver/gpio.h"
#include "esp_log.h"
#include "esp_timer.h"
#include "freertos/FreeRTOS.h"
#include "freertos/task.h"
#include "freertos/queue.h"
#include <string.h>
#include <math.h>

static const char *TAG = "cw";

// ─── MPR121 register map ──────────────────────────────────────────────────────
#define MPR_TOUCH_LO    0x00
#define MPR_TOUCH_HI    0x01
#define MPR_MHD_R       0x2B
#define MPR_NHD_R       0x2C
#define MPR_NCL_R       0x2D
#define MPR_FDL_R       0x2E
#define MPR_MHD_F       0x2F
#define MPR_NHD_F       0x30
#define MPR_NCL_F       0x31
#define MPR_FDL_F       0x32
#define MPR_NHD_T       0x33
#define MPR_NCL_T       0x34
#define MPR_FDL_T       0x35
#define MPR_DEBOUNCE    0x5B
#define MPR_AFE1        0x5C
#define MPR_AFE2        0x5D
#define MPR_ECR         0x5E
// Threshold registers: 0x41 + 2*n = ELEn touch, 0x42 + 2*n = ELEn release
#define MPR_ELE_TOUCH(n) (0x41 + (n)*2)
#define MPR_ELE_RELEASE(n) (0x42 + (n)*2)

// Sensitivity tuning (lower = more sensitive)
#define TOUCH_THR    10    // touch  threshold for ring electrodes
#define RELEASE_THR   6    // release threshold

// ─── Ring geometry helpers ────────────────────────────────────────────────────
// ELE0 = 0° (12 o'clock), clockwise.
// Physical ring: ELE n centre at n * 30°
static inline float ele_centre_deg(int n)
{
    return (float)(n * CW_DEGREES_PER_ZONE);   // 0°, 30°, 60° … 330°
}

/**
 * Weighted circular centroid of active electrodes.
 * Uses baseline-relative "delta" (proximity) to weight each electrode.
 *
 * Returns angle 0–359.9°, or -1 if no electrodes active.
 */
static float compute_centroid(const uint16_t filtered[12])
{
    // Sum sin / cos components (handles 0°/360° wrap)
    float sx = 0, sy = 0, total = 0;
    for (int i = 0; i < 12; i++) {
        if (filtered[i] == 0) continue;
        float w   = (float)filtered[i];
        float rad = ele_centre_deg(i) * (float)M_PI / 180.0f;
        sx   += w * cosf(rad);
        sy   += w * sinf(rad);
        total += w;
    }
    if (total < 1.0f) return -1.0f;
    float angle = atan2f(sy, sx) * 180.0f / (float)M_PI;
    if (angle < 0) angle += 360.0f;
    return angle;   // 0–360°
}

// ─── State ────────────────────────────────────────────────────────────────────
static QueueHandle_t  s_evt_q;
static QueueHandle_t  s_irq_q;

// Ring state (updated in mpr_task, read by UI)
static volatile cw_ring_state_t s_ring;
static volatile uint16_t        s_raw_touch = 0;

// Rotation tracking
static float    s_last_angle    = -1.0f;   // previous centroid (-1 = no touch)
static int32_t  s_accum_deg     = 0;       // accumulated degrees since last tick
static uint32_t s_last_touch_ms = 0;
static int16_t  s_velocity      = 0;

// Sensitivity: ticks per full rotation (default 24 → one tick per 15°)
static uint8_t  s_sensitivity   = 24;
static bool     s_haptic        = false;

// ─── I2C helpers ─────────────────────────────────────────────────────────────
static inline esp_err_t mpr_wr(uint8_t reg, uint8_t val)
{
    uint8_t b[2] = {reg, val};
    return i2c_master_write_to_device(I2C_PORT, MPR121_ADDR, b, 2,
                                       pdMS_TO_TICKS(5));
}
static inline esp_err_t mpr_rd(uint8_t reg, uint8_t *out, size_t len)
{
    return i2c_master_write_read_device(I2C_PORT, MPR121_ADDR,
                                         &reg, 1, out, len,
                                         pdMS_TO_TICKS(5));
}
static uint16_t mpr_touch_status(void)
{
    uint8_t lo = 0, hi = 0;
    mpr_rd(MPR_TOUCH_LO, &lo, 1);
    mpr_rd(MPR_TOUCH_HI, &hi, 1);
    return ((uint16_t)(hi & 0x1F) << 8) | lo;  // 12 electrode bits + ELEPROX
}

// ─── MPR121 init ─────────────────────────────────────────────────────────────
static esp_err_t mpr121_init(void)
{
    // Soft reset
    mpr_wr(0x80, 0x63);
    vTaskDelay(pdMS_TO_TICKS(5));
    // Must be in stop mode to configure
    mpr_wr(MPR_ECR, 0x00);

    // Baseline tracking filter
    mpr_wr(MPR_MHD_R, 0x01);
    mpr_wr(MPR_NHD_R, 0x01);
    mpr_wr(MPR_NCL_R, 0x0E);
    mpr_wr(MPR_FDL_R, 0x00);
    mpr_wr(MPR_MHD_F, 0x01);
    mpr_wr(MPR_NHD_F, 0x05);
    mpr_wr(MPR_NCL_F, 0x01);
    mpr_wr(MPR_FDL_F, 0x00);
    mpr_wr(MPR_NHD_T, 0x00);
    mpr_wr(MPR_NCL_T, 0x00);
    mpr_wr(MPR_FDL_T, 0x00);

    // Thresholds for all 12 electrodes (ELE0–ELE11)
    for (int i = 0; i < 12; i++) {
        mpr_wr(MPR_ELE_TOUCH(i),   TOUCH_THR);
        mpr_wr(MPR_ELE_RELEASE(i), RELEASE_THR);
    }

    // Charge current 16µA, 1µs charge time  (AFE1 = 0xFF, AFE2 = 0x30)
    mpr_wr(MPR_AFE1, 0xFF);
    mpr_wr(MPR_AFE2, 0x30);
    mpr_wr(MPR_DEBOUNCE, 0x00);  // no debounce (handled in firmware)

    // Enable all 12 electrodes; baseline tracking on (CL=10b)
    mpr_wr(MPR_ECR, 0x8C);

    ESP_LOGI(TAG, "MPR121 OK - 12-zone ring active");
    return ESP_OK;
}

// ─── Baseline-relative proximity per electrode ───────────────────────────────
// MPR121 baseline registers: 0x1E + n, stored as (baseline >> 2)
static uint16_t ele_proximity(int n)
{
    // Read electrode filtered data (10-bit) minus baseline
    // Filtered data: registers 0x04 + 2*n (lo), 0x05 + 2*n (hi)
    uint8_t lo, hi, bl;
    uint8_t fd_reg = 0x04 + (uint8_t)(n * 2);
    uint8_t bl_reg = 0x1E + (uint8_t)n;
    mpr_rd(fd_reg,   &lo, 1);
    mpr_rd(fd_reg+1, &hi, 1);
    mpr_rd(bl_reg,   &bl, 1);
    uint16_t filtered  = ((uint16_t)(hi & 0x03) << 8) | lo;
    uint16_t baseline  = (uint16_t)bl << 2;
    return (baseline > filtered) ? (baseline - filtered) : 0;
}

// ─── Angular delta with wrap ──────────────────────────────────────────────────
static float angular_delta(float from, float to)
{
    // Returns delta in (-180, +180]: positive = CW, negative = CCW
    float d = to - from;
    while (d >  180.0f) d -= 360.0f;
    while (d < -180.0f) d += 360.0f;
    return d;
}

// ─── Emit rotation event ─────────────────────────────────────────────────────
static void emit_rotate(cw_event_type_t dir, uint16_t angle, int16_t vel,
                         uint16_t zone_mask)
{
    cw_event_t e = {
        .type         = dir,
        .timestamp_ms = (uint32_t)(esp_timer_get_time() / 1000),
        .angle_deg    = angle,
        .zone         = (uint8_t)((angle + 15) / 30 % 12),
        .velocity     = vel,
        .zone_mask    = zone_mask,
    };
    xQueueSendFromISR(s_evt_q, &e, NULL);
}

// ─── MPR121 IRQ + processing task ────────────────────────────────────────────
static void IRAM_ATTR mpr_irq_isr(void *arg)
{
    uint32_t dummy = 0;
    xQueueSendFromISR(s_irq_q, &dummy, NULL);
}
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

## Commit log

2026-06-04 clickwheel: capacitive click-wheel daughterboard (KiCad 10)
    MPR121-based touch wheel with a 12-segment electrode ring, center pad,
    and five tactile buttons (Menu / Prev / Next / Play / Center) on a
    separate board that cables back to the main board.
    [clickwheel.kicad_pcb, clickwheel.kicad_sch, clickwheel.step]
2026-06-05 case: 3D-printed enclosure model
    Front and back shells modeled in Fusion 360 around the board STEP:
    display window, USB-C slot, click-wheel recess, internal standoffs.
2026-06-17 aeropod2: main board schematic and 4-layer PCB (KiCad 10)
    ESP32-WROOM-32 with hierarchical sheets for power (USB-C, TP4056,
    AMS1117, MT3608 boost), audio (PCM5102A I2S DAC), display, input, and
    microSD storage. 4-layer board, about 41 x 90 mm.
    [aeropod2.kicad_pcb, aeropod2.kicad_sch, audio.kicad_sch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]
2026-06-30 firmware: ESP-IDF app - display, UI, audio, video, Spotify, Bluetooth
    C firmware on ESP-IDF v5.2: SPI display driver, stack-based iPod-style
    UI at ~33 fps, SD media library (Artists/Albums/Tracks), MP3 playback
    via minimp3 on its own core, MJPEG video via TJpgDec, Wi-Fi manager,
    Spotify (OAuth PKCE, Web API, Spotify Connect over mDNS), and
    Bluetooth A2DP with Wi-Fi/BT software coexistence.
    [partitions.csv]
2026-07-17 Switch display to ST7789 IPS (240x320 SPI)
    Replaces the ILI9341 driver with an ST7789 driver targeting a
    Waveshare 2" 240x320 SPI IPS panel. The command set (CASET, RASET,
    RAMWR, MADCTL, COLMOD) is shared between the two controllers, so the
    public display.h API and every drawing/text/blit routine in
    display.c are unchanged. Only the low level init register sequence
    and panel specific commands were swapped.
    Also updates config.h, main.c splash/about text, the video player
    byte swap comment, and the README/BUILD/parts list references from
    ILI9341 to ST7789.
    Panel colour order (RGB vs BGR) and the INVON/INVOFF choice in
    st7789_init_regs() may need a one line tweak once tested against
    the real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
    [config.h, display.c, main.c]
2026-07-17 Add fabrication outputs, printable case, and assembly guide
    - Gerbers + drill files for both boards (aeropod2/gerbers, clickwheel/gerbers)
    - BOM, pick-and-place positions, and JLC-ready zips in each production/ folder
    - case/Aeropod_Case.step + .stl (both shells on one printable plate)
    - ASSEMBLY.md with the step-by-step assembly plan; README fabrication section
    [Aeropod_Case.step, Aeropod_Case.stl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]
2026-07-17 Assembly: hot glue mounting and cardstock backing for the click wheel
    The PCBs have no mounting holes, so screws are out: the main board and
    battery are hot glued into the back shell and the case halves are glued
    at the seam. The click-wheel board is not glued at all - it is held by
    pressure against a cardstock/cardboard backing sheet that gives the
    tactile buttons a surface to press against, with hot glue dams around
    its edge to stop it sliding. The backing thickness is intentionally not
    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
2026-08-06 Add bill of materials and Fusion 360 case source
    bom.csv lists every part with quantity, unit price, and a purchase link,
    split into the build cost (boards, display, battery, card, cable, glue,
    cardstock) and the components the assembly house places on the two
    boards. The same build cost table is in the README.
    Also adds case/Aeropod_Case.f3d so the enclosure can be edited rather
    than only printed.
    [Aeropod_Case.f3d, bom.csv]
2026-08-06 Fix schematic faults found in electrical review, add reset/boot buttons
    Four faults would have stopped the main board working:
    - EN had no pull-up. R4/C5 sat on the unused throw of SW1 while EN was
    left holding only an AC coupled cap, so the module would not have
    booted. R4/C5 now sit on EN, and SW1/SW2 are momentary buttons to
    ground instead of slide switches.
    - The microSD was miswired: connections shifted by one pin and CMD tied
    to GND, so no card could ever initialise. The display data line also
    shared a net with the card's DAT0 output. CS now lands on DAT3/CD,
    CMD on IO23 alongside the display, and IO19 is MISO from the card
    alone.
    - The boost inductor was never connected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
    [audio.kicad_sch, bom.csv, display.kicad_sch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]
2026-08-07 Drop button pull-ups and backlight pin, clear ERC, vendor CP2102N footprint
    The five button pull-ups are gone. The only line that actually needed one
    was B5, because it sat on GPIO35 and GPIO34-39 are input only with no
    internal pull-up. B5 now sits on GPIO33, a full GPIO, so the ESP32's own
    pull-ups hold all five buttons high and R20-R24 are removed. GPIO35 is
    spare.
    The display connector goes back to seven pins. There is no backlight
    control line, so the module's BL input is tied to 3.3 V and runs at full
    brightness. The LEDC setup is removed and display_backlight() is a no-op
    so callers do not change.
    The five power_pin_not_driven errors are now properly resolved with
    PWR_FLAGs on GND,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
    [audio.kicad_sch, bom.csv, display.kicad_sch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]
2026-08-07 Use ultra-small tactile buttons for reset and boot
    SW1 and SW2 were on the Omron B3S-1000, whose footprint outline is
    10 x 7.4 mm with four pads including the mounting tabs. Swapped to the
    B3U-1000P: 3.0 x 2.5 mm body, 1.6 mm tall, two 0.9 x 1.7 mm pads on a
    3.4 mm pitch, which is the size used on ESP32 dev boards.
    The symbol was already Switch:SW_Push, a two pin momentary button, so
    only the footprint changes. The clickwheel board keeps the larger 6 x 6
    part for the five user facing buttons, which are pressed through the
    case.
    Schematic still passes ERC with 0 errors and 0 warnings, 67 components,
    and every footprint resolves.
    [bom.csv, esp32.kicad_sch]
2026-08-10 Revert schematic, PCB and firmware to the hand-drawn version
    Restores aeropod2/*.kicad_sch, aeropod2.kicad_pcb, the firmware pin map
    and the BOM to their state at d6429d0, which is byte identical to the
    last human-edited revision (2867710). The corrected schematic is still
    in history at b35a9fa if any of it is wanted later.
    The board file had picked up R18/R19 and the tactile switch footprints
    from a schematic update. Nothing hand-made was lost reverting it: track
    and via counts were unchanged at 894/147 and the two new parts were
    sitting at KiCad's default drop position.
    ELECTRICAL_REVIEW.md is rewritten to describe the faults as they stand
    in this schematic, and to give the smallest set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
    [audio.kicad_sch, bom.csv, display.kicad_sch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]
2026-08-23 Rework the power options around battery life, not just correctness
    The boost-then-LDO path on this board is the worst of the available
    options for runtime: the MT3608 converts at about 88 percent and the
    AMS1117 then burns the 4.8 V to 3.3 V difference as heat, so roughly 60
    percent of the cell reaches the load. Repairing it is both the most
    layout work and the least battery.
    Documents four alternatives with rough energy numbers instead. The
    default recommendation is now to delete the boost entirely and swap the
    AMS1117 for an AP2114H-3.3, which is the same SOT-223 footprint and pin
    order, needs no layout change, and still delivers more energy than the
    repaired boost. Notes the AP2114HA var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
    [audio.kicad_sch, esp32.kicad_sch, storage.kicad_sch]
2026-08-23 Add a proper power section design guide
    Guidance only, no schematic changes. Describes replacing the diode OR
    and boost-then-LDO chain with a two stage design: a BQ24074 linear
    charger with a real power path feeding a TPS63020 single inductor
    buck-boost.
    Covers the ISET, ILIM and TMR resistor calculations for the charger, the
    feedback divider, inductor and capacitor selection for the converter,
    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
2026-08-27 Restore the design files to the shipped revision
    The earlier revert did not fully land: KiCad had the edited sheets open
    and re-saved them over the restored files, so parts of the SD rewiring
    and the B5 pin move were still present in audio, esp32 and storage.
    All schematics, the board file and the firmware are now restored from
    d6429d0 and verified by netlist comparison rather than by diffing text.
    89 nets, electrically identical to the revision the gerbers and
    production files were generated from. The SD socket is back to its
    original wiring and the in-progress BQ24074 power work is reverted.
    Also clears two stale KiCad lock files.
    [audio.kicad_sch, esp32.kicad_sch, storage.kicad_sch]
